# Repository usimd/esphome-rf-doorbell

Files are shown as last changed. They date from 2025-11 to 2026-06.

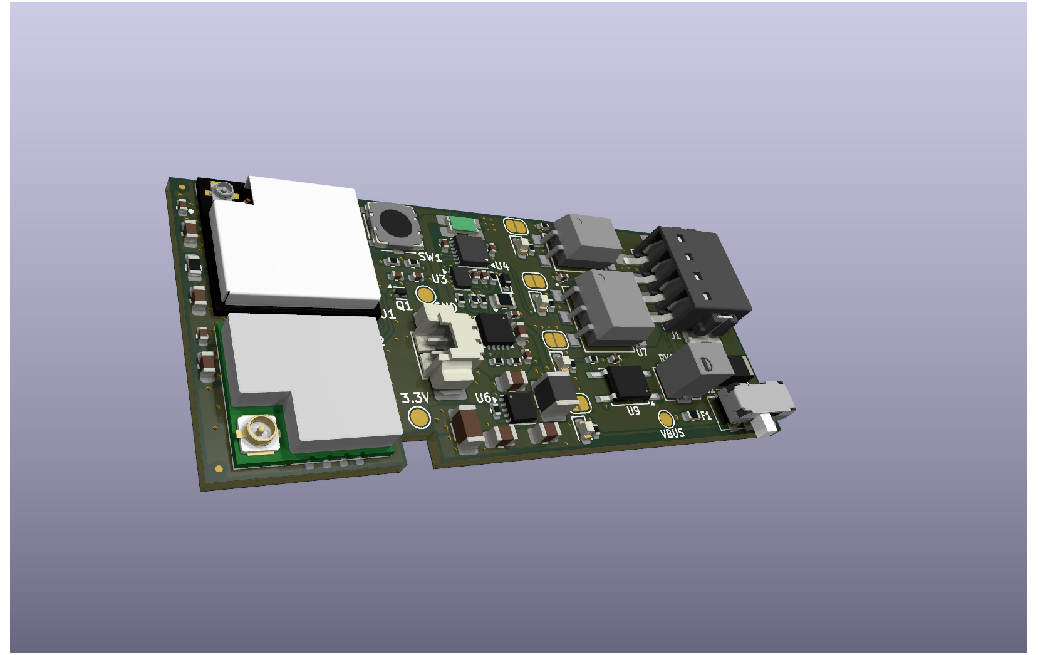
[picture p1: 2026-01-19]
base/esphome-rf-doorbell.png

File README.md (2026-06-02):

# ESPHome RF Doorbell





Battery-powered ESPHome doorbell hardware and firmware centered on the current Rev3 base board.

## Current Scope

- `base/` is the active hardware target.
- `esphome/doorbell.yaml` is the active firmware target.
- Rev3 uses ESP32-C6, LTC4079, ISL23315, MAX17260, and ESPHome's built-in `sx126x` support.
- `remote/` is intentionally kept as unfinished WIP hardware. It is not a supported production target.

## Rev3 Hardware Summary

| Ref | Part | Purpose |
|-----|---|---|
| U1 | LTC4079 | Li-ion charger |
| U3 | TPS63900 | Low-power buck-boost regulator |
| U4 | MAX17260 | Fuel gauge |
| U5 | LTV-354T | Doorbell input optocoupler |
| U6 | G3VM-31DR | Door opener relay |
| U7 | Wio-SX1262 | SX1262 radio module |
| U8 | G3VM-63ER | Bell mute relay |
| U9 | ESP32-C6-MINI-1 | Main MCU |
| U10 | ISL23315 | Digipot for charger control |

The base board already includes an SX126x receive path and that remains part of the intended design, even though the remote side is still unfinished.

## Repository Layout

```text
base/                    Active Rev3 KiCad project
datasheets/              Datasheets and hardware notes used during development
esphome/                 Active ESPHome firmware
esphome/components/      Custom ESPHome components
lib/                     Project KiCad footprints and symbols
remote/                  Unfinished remote hardware kept as WIP
```

## Firmware

The active firmware is in `esphome/doorbell.yaml`.

Implemented custom components:

- `doorbell_controller`: charger control, supply sensing, runtime sleep duration control
- `max17260`: fuel gauge driver with POR handling and learned-parameter persistence

Radio support uses ESPHome's built-in `sx126x` component rather than a custom RF stack.

## Build

From `esphome/`:

```bash
esphome compile doorbell.yaml
```

The configuration expects `esphome/secrets.yaml` to exist locally.

## Status

- Legacy firmware and custom components are removed from the supported path.
- The active Rev3 ESPHome config compiles successfully.
- CI builds the Rev3 firmware and the base KiCad project.
- `remote/` remains a hardware placeholder for future work and still contains legacy symbols/footprints inside that WIP design.

## Notes

- The ESP32-C6 pin usage in this design currently triggers ESPHome warnings for USB-Serial-JTAG pins and strapping pins. Those warnings reflect the current hardware choices and should be kept in mind during bring-up.
- `esphome/charging_test.yaml` and `esphome/charging_test_simple.yaml` currently exist as untracked placeholders and are not part of the supported firmware path.

## AISLER discount

In case you want to order this (or any other) project at AISLER, here's a 10€ discount code: `MakeInEurope-ZDCTN`

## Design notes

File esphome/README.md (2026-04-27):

# ESPHome Firmware

This directory contains the active Rev3 firmware for the base doorbell board.

## Active Files

- `doorbell.yaml`: main configuration used for builds
- `components/doorbell_controller/`: charger and power-management helper component
- `components/max17260/`: MAX17260 fuel gauge component
- `secrets.yaml`: local machine-specific secrets, ignored by git

## Rev3 Firmware Model

The supported firmware path is built around:

- ESP32-C6
- LTC4079 charger with ISL23315 digipot control
- MAX17260 fuel gauge
- ESPHome `sx126x` integration for the Wio-SX1262 module
- deep sleep wakeups from bell input, SX1262 DIO1, battery alert, and timer

There is no supported legacy firmware configuration in this directory anymore.

## Build

```bash
esphome compile doorbell.yaml
```

## OTA Recovery Helper

When the installed node is only reachable during short wake windows, use the repo-local helper to press the ESPHome `Restart` button over the native API and force the device into its existing `cold_boot_ota_window`.

```bash
../.venv/bin/python restart_into_ota_window.py --restart
```

Without `--restart`, the helper only prints the live device metadata and available button entities.
Add `--wait-timeout 180` if you want it to keep polling through the current deep-sleep cycle until the device wakes up.
The helper prefers `esphome-rf-doorbell.local` by default because the active firmware does not currently configure a fixed `manual_ip`.

## Runtime Notes

- `doorbell_controller` updates the real `deep_sleep` component sleep duration at runtime.
- `max17260` restores learned parameters from preferences and now treats POR-read failures as setup failures instead of healthy state.
- The firmware intentionally uses local external components from `components/`.

## Known Bring-Up Warnings

ESPHome currently warns that some selected GPIOs are USB-Serial-JTAG or strapping pins on ESP32-C6. These warnings are expected with the present hardware design and do not indicate a configuration parse failure.

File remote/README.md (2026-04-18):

# Remote WIP

`remote/` is intentionally kept as unfinished hardware work.

- It is not a supported production target.
- The old remote firmware implementation was removed.
- The current schematic and PCB may still contain legacy placeholder parts from earlier RF exploration.
- Keep this directory as hardware WIP until the remote architecture is redesigned around the current project direction.

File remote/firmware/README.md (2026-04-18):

# Remote Firmware WIP

There is currently no supported remote firmware implementation in this repository.

The previous remote firmware sources were removed. The remaining files in this directory are only leftover project workspace artifacts or reusable MCU-codegen scaffolding for future remote experiments.

Do not treat this directory as a buildable or supported firmware target in its current state.

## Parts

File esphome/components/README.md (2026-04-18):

# ESPHome Custom Components

This directory contains the custom components used by the active Rev3 firmware.

## Components

### `doorbell_controller`

Controls the LTC4079 support circuitry around the ISL23315 digipot and exposes:

- VINDPM threshold control
- charging enable/disable
- charge-disable override
- supply voltage measurement
- charge current estimation from `V_PROG`
- runtime deep sleep duration control

This component explicitly re-enables the ESP-IDF `esp_adc` component because ESPHome excludes it by default for faster builds.

### `max17260`

Fuel gauge driver for the MAX17260 with support for:

- battery percentage
- voltage, current, temperature
- remaining/full capacity
- cycle count
- time-to-empty and time-to-full
- device name and serial number
- POR detection and reinitialization
- persistence of learned parameters in ESPHome preferences

## Loading

`doorbell.yaml` loads both components from the local `components/` directory via `external_components`.

## Support Boundary

Only `doorbell_controller` and `max17260` are part of the supported Rev3 path here. Legacy custom components were removed from this repository path.

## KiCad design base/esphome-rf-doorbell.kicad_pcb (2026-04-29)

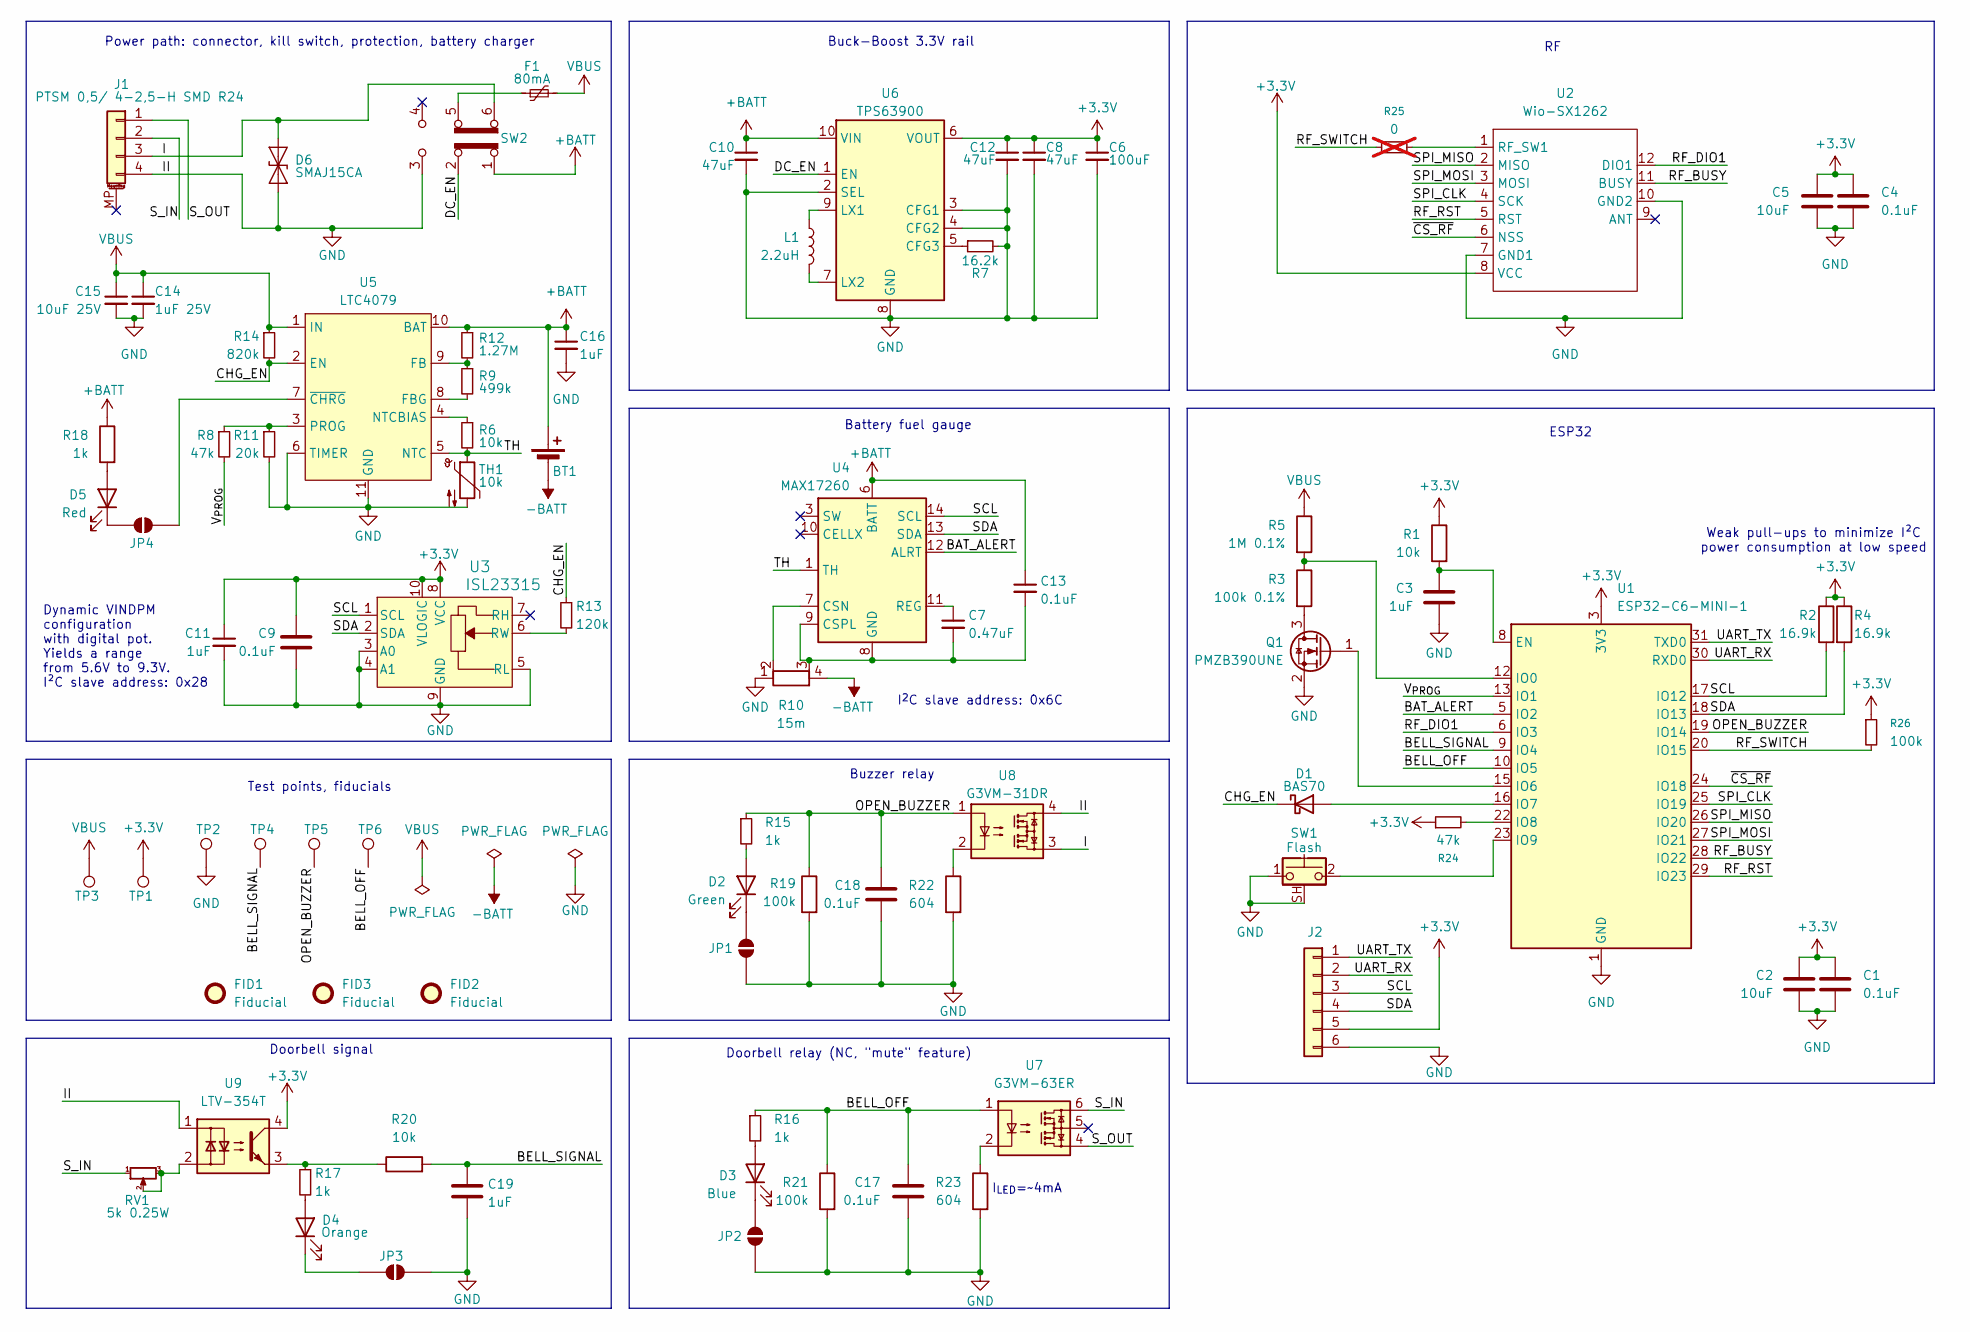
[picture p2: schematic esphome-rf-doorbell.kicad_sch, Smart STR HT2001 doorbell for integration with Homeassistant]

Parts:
BT1: Molex_PicoBlade_53261-0271_1x02-1MP_P1.25mm_Horizontal; MPN 532610271
C1, C4, C9, C13, C17, C18: 0.1uF; C_0402_1005Metric
C2, C5: 10uF; C_0603_1608Metric
C3: 1uF; C_0603_1608Metric
C6: 100uF; C_1206_3216Metric
C7: 0.47uF; C_0402_1005Metric
C8, C10, C12: 47uF; C_0805_2012Metric
C11, C16, C19: 1uF; C_0402_1005Metric
C14: 1uF 25V; C_0402_1005Metric
C15: 10uF 25V; C_0603_1608Metric
D1: BAS70; D_SOD-523; MPN BAS7002VH6327XTSA1
D2: Green; LED_0603_1608Metric
D3: Blue; LED_0603_1608Metric
D4: Orange; LED_0603_1608Metric
D5: Red; LED_0603_1608Metric
D6: SMAJ15CA; D_SMA; MPN SMAJ15CA
F1: 80mA; Fuse_0603_1608Metric; MPN SMD0603B008TF
FID1, FID2, FID3: Fiducial; Fiducial_0.5mm_Mask1mm
J1: PTSM 0,5/ 4-2,5-H SMD R24; PHOENIX_1702474; MPN 1702474
J2: Conn_01x06; Connector_PogoClamp_1.27mm
JP1, JP2, JP3, JP4: SolderJumper_2_Open; SolderJumper-2_P1.3mm_Open_RoundedPad1.0x1.5mm
L1: 2.2uH; L_1210_3225Metric; MPN DFE32CAH2R2MR0L
Q1: PMZB390UNE; Diodes_DFN1006-3; MPN PMZB390UNEYL
R1: 10k; R_0603_1608Metric
R2, R4: 16.9k; R_0402_1005Metric
R3: 100k 0.1%; C_0402_1005Metric
R5: 1M 0.1%; C_0402_1005Metric
R6, R20: 10k; R_0402_1005Metric
R7: 16.2k; R_0402_1005Metric
R8: 47k; R_0402_1005Metric
R9: 499k; R_0402_1005Metric
R10: 15m; R_Shunt_D1WRL1206; MPN D1WRL1206L4R015D-T5
R11: 20k; R_0402_1005Metric
R12: 1.27M; R_0402_1005Metric
R13: 120k; R_0402_1005Metric
R14: 820k; R_0805_2012Metric
R15, R16, R17, R18: 1k; R_0402_1005Metric
R19, R21: 100k; R_0402_1005Metric
R22, R23: 604; R_0402_1005Metric
R24: 47k; C_0402_1005Metric
R25: 0; C_0402_1005Metric; not fitted
R26: 100k; C_0402_1005Metric
RV1: 5k 0.25W; Potentiometer_Bourns_3214W_Vertical; MPN 3214W-1-502E
SW1: Flash; SW_SPST_Panasonic_EVQPL_3PL_5PL_PT_A08; MPN TVCU18015BPB
SW2: CL-SB-22A-11T; CL-SB-22A; MPN CL-SB-22A-11T
TH1: 10k; R_0603_1608Metric; MPN NTCS0603E3103FLT
TP1, TP2, TP3, TP4, TP5, TP6: TestPoint; TestPoint_Pad_D1.5mm
U1: ESP32-C6-MINI-1; XCVR_ESP32-C6-MINI-1U-N4; MPN ESP32-C6-MINI-1U-N4
U2: Wio-SX1262; Wio-SX1262 PCB Package; MPN WIO-SX1262
U3: ISL23315; L10_2P1X1P6A_INR; MPN ISL23315TFRUZ-T7A
U4: MAX17260; TDFN-14-1EP_3x3mm_P0.4mm_EP1.78x2.35mm; MPN MAX17260SETD+
U5: LTC4079; DFN-10-1EP_3x3mm_P0.5mm_EP1.65x2.38mm; MPN LTC4079EDD#TRPBF
U6: TPS63900; WSON-10-1EP_2.5x2.5mm_P0.5mm_EP1.2x2mm_ThermalVias; MPN TPS63900DSKR
U7: G3VM-63ER; G3VM-21ER; MPN G3VM-63ER
U8: G3VM-31DR; G3VM-21DR; MPN G3VM-31DR
U9: LTV-354T; SO-4_4.4x3.6mm_P2.54mm; MPN LTV-354T

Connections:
+3.3V: C1.1, C2.1, C4.1, C5.1, C6.1, C8.1, C9.1, C11.1, C12.1, J2.5, R1.1, R2.1, R4.1, R24.1, R26.1, TP1.1 (1_1), U1.3 (3V3), U2.8 (VCC), U3.8 (VCC), U3.10 (VLOGIC), U6.6 (VOUT), U9.4
+BATT: BT1.1 (+), C10.1, C13.1, C16.1, R12.1, R18.1, SW2.1 (A), U4.6 (BATT), U5.10 (BAT), U6.10 (VIN)
-BATT: BT1.2 (-), R10.4
/BAT_ALERT: U1.5 (IO2), U4.12 (ALRT)
/BELL_OFF: C17.1, R16.1, R21.1, TP6.1 (1_1), U1.10 (IO5), U7.1
/BELL_SIGNAL: C19.1, R20.2, TP4.1 (1_1), U1.9 (IO4)
/CHG_EN: D1.1 (K), R13.1, R14.2, U5.2 (EN)
/DC_EN: SW2.2 (B), U6.1 (EN)
/I: D6.2 (A2), J1.3, SW2.6 (C), U8.3
/OPEN_BUZZER: C18.1, R15.1, R19.1, TP5.1 (1_1), U1.19 (IO14), U8.1
/RF_BUSY: U1.28 (IO22), U2.11 (BUSY)
/RF_DIO1: U1.6 (IO3), U2.12 (DIO1)
/RF_RST: U1.29 (IO23), U2.5 (RST)
/RF_SWITCH: R25.1, R26.2, U1.20 (IO15)
/SCL: J2.3, R2.2, U1.17 (IO12), U3.1 (SCL), U4.14 (SCL)
/SDA: J2.4, R4.2, U1.18 (IO13), U3.2 (SDA), U4.13 (SDA)
/SPI_CLK: U1.25 (IO19), U2.4 (SCK)
/SPI_MISO: U1.26 (IO20), U2.2 (MISO)
/SPI_MOSI: U1.27 (IO21), U2.3 (MOSI)
/S_IN: J1.2, RV1.1, U7.6
/S_OUT: J1.1, U7.4
/TH: R6.2, TH1.1, U4.1 (TH), U5.5 (NTC)
/UART_RX: J2.2, U1.30 (RXD0)
/UART_TX: J2.1, U1.31 (TXD0)
/V_{PROG}: R8.2, U1.13 (IO1)
/~CS_RF: U1.24 (IO18), U2.6 (NSS)
GND: C1.2, C2.2, C3.2, C4.2, C5.2, C6.2, C8.2, C9.2, C10.2, C11.2, C12.2, C14.2, C15.2, C16.2, C17.2, C18.2, C19.2, D6.1 (A1), J1.4, J2.6, JP1.1 (A), JP2.1 (A), JP3.2 (B), Q1.2 (S), R7.2, R10.1, R11.2, R19.2, R21.2, R22.2, R23.2, SW1.1, SW1.SH (B), SW2.3 (C), TH1.2, TP2.1 (1_1), U1.1 (GND), U1.2 (GND), U1.11 (GND), U1.14 (GND), U1.36 (GND), U1.37 (GND), U1.38 (GND), U1.39 (GND), U1.40 (GND), U1.41 (GND), U1.42 (GND), U1.43 (GND), U1.44 (GND), U1.45 (GND), U1.46 (GND), U1.47 (GND), U1.48 (GND), U1.49 (GND), U1.50 (GND), U1.51 (GND), U1.52 (GND), U1.53 (GND), U2.7 (GND1), U2.10 (GND2), U3.3 (A0), U3.4 (A1), U3.5 (RL), U3.9 (GND), U5.6 (TIMER), U5.11 (GND), U6.2 (SEL), U6.3 (CFG1), U6.4 (CFG2), U6.8 (GND), U6.11 (GND), U8.4, U9.1
unnamed: D1.2 (A), U1.16 (IO7)
unnamed: D2.2 (A), R15.2
unnamed: D2.1 (K), JP1.2 (B)
unnamed: D3.2 (A), R16.2
unnamed: D3.1 (K), JP2.2 (B)
unnamed: D4.2 (A), R17.2
unnamed: D4.1 (K), JP3.1 (A)
unnamed: D5.2 (A), R18.2
unnamed: D5.1 (K), JP4.2 (B)
unnamed: F1.1, SW2.5 (B)
unnamed: JP4.1 (A), U5.7 (~CHRG)
unnamed: Q1.3 (D), R3.2
unnamed: Q1.1 (G), U1.15 (IO6)
unnamed: R17.1, R20.1, U9.3
unnamed: R22.1, U8.2
unnamed: R23.1, U7.2
unnamed: RV1.2, RV1.3, U9.2
unnamed: C3.1, R1.2, U1.8 (EN)
unnamed: R3.1, R5.2, U1.12 (IO0)
unnamed: R24.2, U1.22 (IO8)
unnamed: SW1.2, U1.23 (IO9)
unnamed: R25.2, U2.1 (RF_SW1)
unnamed: R13.2, U3.6 (RW)
unnamed: R10.2, U4.7 (CSN)
unnamed: C7.2, C13.2, R10.3, U4.8 (GND), U4.9 (CSPL), U4.15 (GND)
unnamed: C7.1, U4.11 (REG)
unnamed: R9.1, R12.2, U5.9 (FB)
unnamed: R9.2, U5.8 (FBG)
unnamed: R6.1, U5.4 (NTCBIAS)
unnamed: R8.1, R11.1, U5.3 (PROG)
unnamed: R7.1, U6.5 (CFG3)
unnamed: L1.1, U6.9 (LX1)
unnamed: L1.2, U6.7 (LX2)
VBUS: C14.1, C15.1, F1.2, R5.1, R14.1, TP3.1 (1_1), U5.1 (IN)

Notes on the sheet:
Dynamic VINDPM configuration with digital pot. Yields a range from 5.6V to 9.3V. I²C slave address: 0x28
Test points, fiducials
Battery fuel gauge
ESP32
Weak pull-ups to minimize I²C power consumption at low speed
Doorbell signal
I_{LED}=~4mA
Buzzer relay
Doorbell relay (NC, "mute" feature)
Buck-Boost 3.3V rail
Power path: connector, kill switch, protection, battery charger
I^{2}C slave address: 0x6C

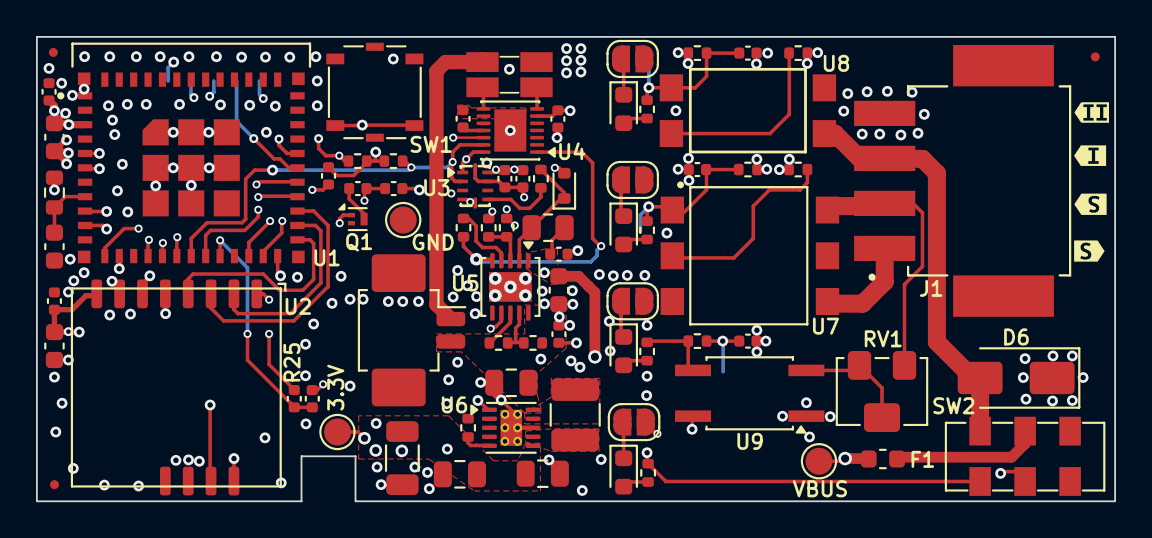
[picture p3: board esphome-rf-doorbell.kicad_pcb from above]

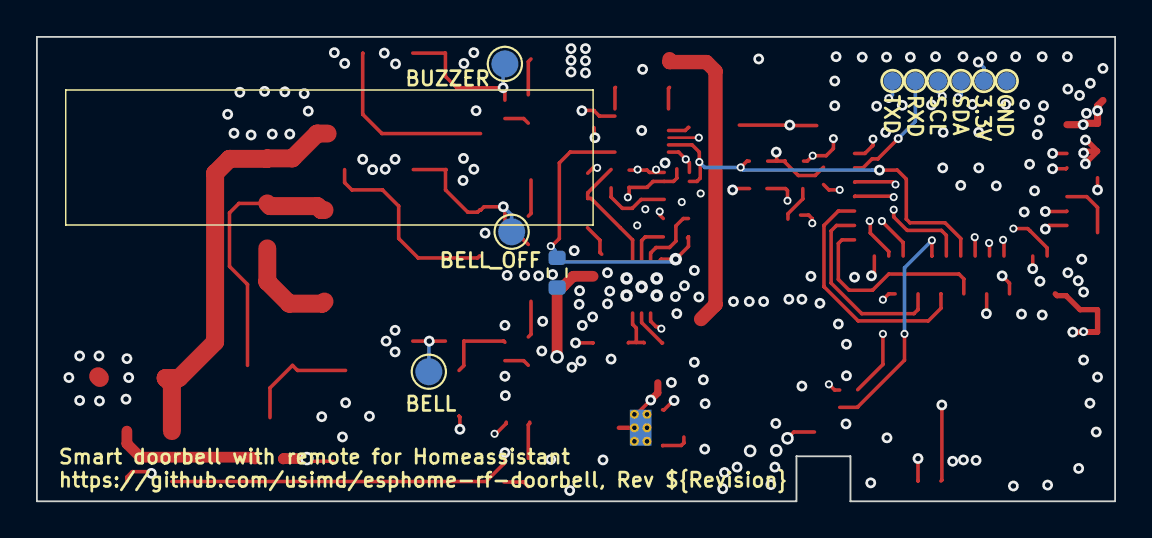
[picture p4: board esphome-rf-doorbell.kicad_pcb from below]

Board: 4 copper layers, 59.9 x 25.8 mm, 87 parts (5 on the bottom side), 61 nets.

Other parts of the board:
kibuzzard-696E5F1B: G***; kibuzzard-696E5F1B
kibuzzard-696E5F3B: G***; kibuzzard-696E5F3B
kibuzzard-696E5F26: G***; kibuzzard-696E5F26
kibuzzard-696E5F32: G***; kibuzzard-696E5F32

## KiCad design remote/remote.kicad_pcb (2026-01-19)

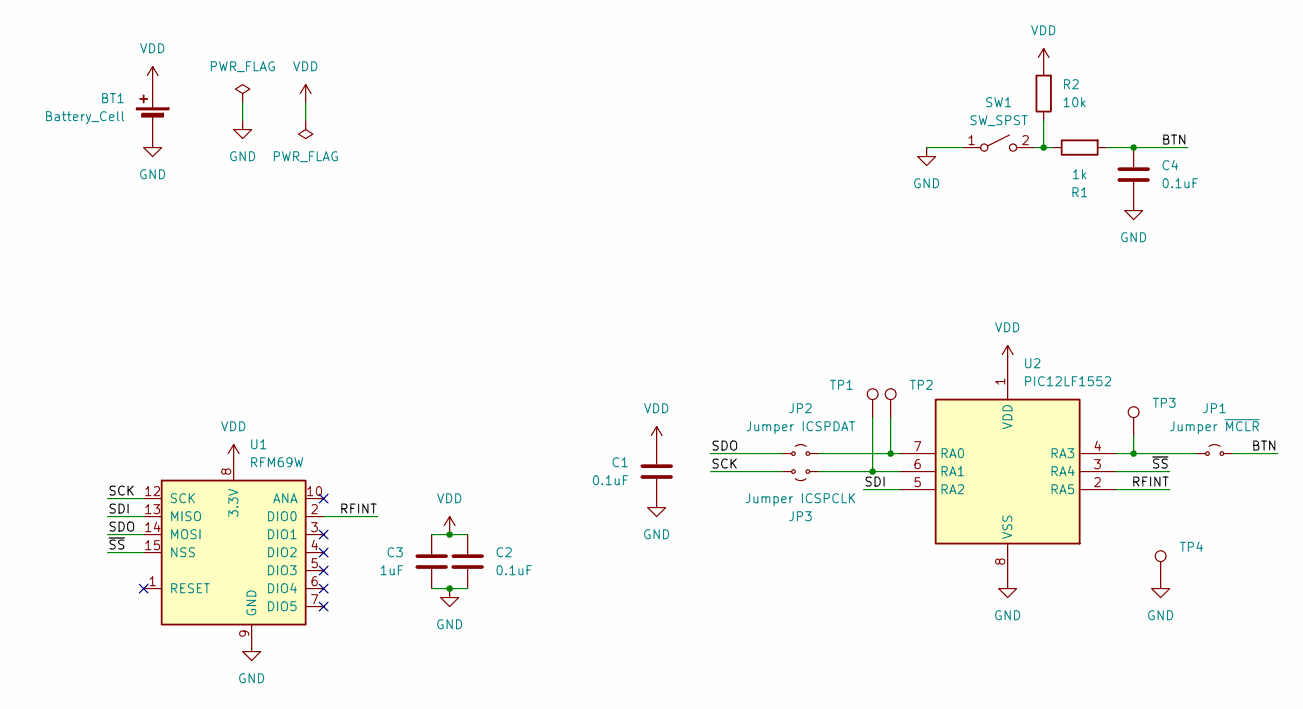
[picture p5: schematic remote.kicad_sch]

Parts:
BT1: Battery_Cell; BatteryHolder_Keystone_1060_1x2032
C1, C2, C4: 0.1uF; C_0603_1608Metric_Pad1.08x0.95mm_HandSolder
C3: 1uF; C_0603_1608Metric_Pad1.08x0.95mm_HandSolder
JP1: Jumper ~{MCLR}; SolderJumper-2_P1.3mm_Open_RoundedPad1.0x1.5mm
JP2: Jumper ICSPDAT; SolderJumper-2_P1.3mm_Open_RoundedPad1.0x1.5mm
JP3: Jumper ICSPCLK; SolderJumper-2_P1.3mm_Open_RoundedPad1.0x1.5mm
R1: 1k; R_0603_1608Metric_Pad0.98x0.95mm_HandSolder
R2: 10k; R_0603_1608Metric_Pad0.98x0.95mm_HandSolder
SW1: SW_SPST; SW_SPST_Panasonic_EVQPL_3PL_5PL_PT_A15
TP1, TP2, TP3, TP4: TestPoint; TestPoint_Keystone_5000-5004_Miniature
U1: RFM69W; HOPERF_RFM69HW
U2: PIC12LF1552; MSOP-8_3x3mm_P0.65mm

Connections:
/BTN: C4.1, JP1.2 (B), R1.2
/RFINT: U1.2 (DIO0), U2.2 (RA5)
/SCK: JP3.1 (A), U1.12 (SCK)
/SDI: U1.13 (MISO), U2.5 (RA2)
/SDO: JP2.1 (A), U1.14 (MOSI)
/~SS: U1.15 (NSS), U2.3 (RA4)
GND: BT1.2 (-), C1.2, C2.2, C3.2, C4.2, SW1.1 (A), TP4.1, U1.9 (GND), U1.11 (GND), U2.8 (VSS)
unnamed: JP1.1 (A), TP3.1, U2.4 (RA3)
unnamed: JP2.2 (B), TP2.1, U2.7 (RA0)
unnamed: JP3.2 (B), TP1.1, U2.6 (RA1)
unnamed: R1.1, R2.1, SW1.2 (B)
VDD: BT1.1 (+), C1.1, C2.1, C3.1, R2.2, U1.8 (3.3V), U2.1 (VDD)

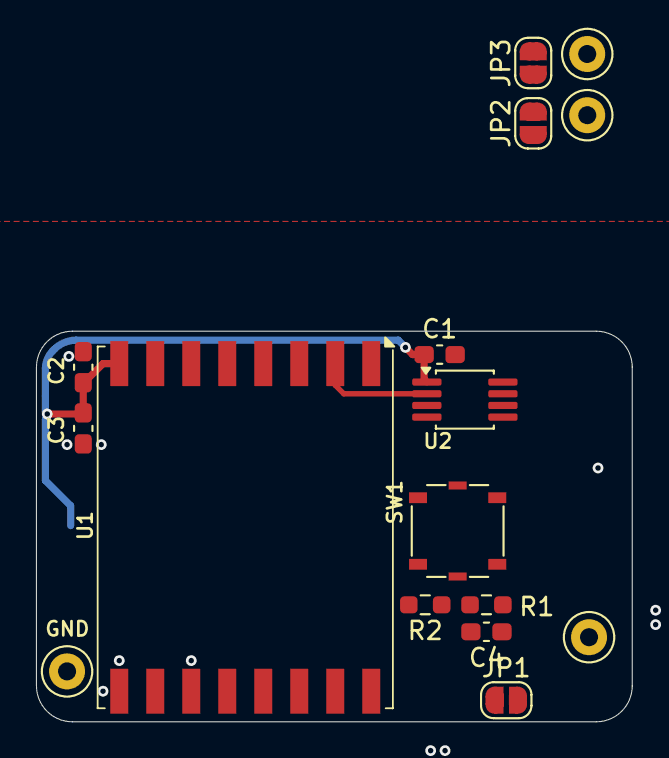
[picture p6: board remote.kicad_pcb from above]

Board: 2 copper layers, 33.1 x 21.7 mm, 17 parts (1 on the bottom side), 12 nets.

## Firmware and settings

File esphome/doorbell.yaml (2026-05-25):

# =============================================================================
# ESPHome RF Doorbell - Rev3 Hardware Configuration
# =============================================================================
# Hardware: ESP32-C6-MINI-1, LTC4079 charger, MAX17260 fuel gauge, Wio-SX1262
# 
# Rev3 hardware summary:
#   - MCU: ESP32-C6-MINI-1
#   - Charger: LTC4079 controlled via ISL23315 digipot
#   - RF: Wio-SX1262 LoRa via ESPHome's sx126x component
#   - Buck: TPS63900 for ultra-low quiescent current
#
# =============================================================================

esphome:
  name: esphome-rf-doorbell
  friendly_name: Doorbell

  includes:
    - components/max17260/max17260.h
  
  on_boot:
    - priority: -100  # Runs last after all components initialized
      then:
        - script.execute: handle_boot_wakeup

# =============================================================================
# ESP32-C6 configuration (Rev3 custom hardware)
# =============================================================================
esp32:
  board: esp32-c6-devkitm-1
  variant: esp32c6
  framework:
    type: esp-idf
    version: recommended

# =============================================================================
# Deep Sleep Configuration for Low Power Operation
# =============================================================================
# Wake sources:
#   1. GPIO4 (Bell Signal) - Doorbell pressed, stay awake 60s for user interaction
#      Uses the ESP32-C6 GPIO wake path because runtime GPIO4 works, but ext1 wake on
#      this pin has been unreliable on bench.
#   2. GPIO2 (BAT_ALERT MAX17260) - Battery alert, update sensor and quick sleep
#      Uses ext1 ANY_LOW because the alert line is open-drain active-low.
#   3. Timer (300s default, HA-controlled) - Periodic sync of HA desired state and diagnostics
# Power target: TPS63900 provides <400nA quiescent, total deep sleep <10uA
# =============================================================================
deep_sleep:
  id: deep_sleep_control
  sleep_duration: 300s
  # On ESP32-C6, runtime GPIO4 sensing works reliably, so use the single-pin GPIO wake
  # path for the bell input and reserve ext1 for the active-low battery alert.
  wakeup_pin:
    number: GPIO4
    mode:
      input: true
      pulldown: true
    inverted: false
    allow_other_uses: true
  wakeup_pin_mode: KEEP_AWAKE
  esp32_ext1_wakeup:
    pins:
      - number: GPIO2   # Battery alert (active LOW open-drain)
        allow_other_uses: true
    mode: ANY_LOW

# Enable logging
logger:
  level: INFO
  baud_rate: 115200
  hardware_uart: UART0

# Time component for timestamps
time:
  - platform: homeassistant
    id: esphome_time

api:
  homeassistant_states: true
  encryption:
    key: !secret doorbell_api_encryption_key

ota:
  - platform: esphome
    password: !secret doorbell_ota_password

wifi:
  ssid: !secret wifi_ssid
  password: !secret wifi_password
  fast_connect: true
  output_power: 15dB
  ap:
    ssid: "Doorbell Fallback Hotspot"
    password: !secret doorbell_ap_password
    ap_timeout: 30s

captive_portal:

# =============================================================================
# Persistent Diagnostics
# =============================================================================
globals:
  - id: wake_count_total
    type: uint32_t
    restore_value: true
    initial_value: '0'

  - id: wake_count_doorbell
    type: uint32_t
    restore_value: true
    initial_value: '0'

  - id: wake_count_timer
    type: uint32_t
    restore_value: true
    initial_value: '0'

  - id: wake_count_battery
    type: uint32_t
    restore_value: true
    initial_value: '0'

  - id: wake_count_cold_boot
    type: uint32_t
    restore_value: true
    initial_value: '0'

  - id: bell_event_count
    type: uint32_t
    restore_value: true
    initial_value: '0'

  - id: last_wake_reason
    type: std::string
    restore_value: true
    max_restore_data_length: 31
    initial_value: '"unknown"'

  - id: last_mute_sync_status
    type: std::string
    restore_value: true
    max_restore_data_length: 31
    initial_value: '"startup"'

  - id: last_bell_millis
    type: uint32_t
    restore_value: false
    initial_value: '0'

# =============================================================================
# External Components
# =============================================================================
external_components:
  - source:
      type: local
      path: components
    components: [max17260, doorbell_controller]

# =============================================================================
# I2C Bus (shared by doorbell_controller and max17260)
# =============================================================================
i2c:
  sda: GPIO13
  scl: GPIO12
  frequency: 100kHz  # Lower frequency for weak pull-ups on PCB
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

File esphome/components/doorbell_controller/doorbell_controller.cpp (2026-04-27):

#include "doorbell_controller.h"
#include "esphome/core/log.h"
#include "esphome/core/application.h"

#ifdef USE_ESP32
#include "esp_sleep.h"
#include "esp_adc/adc_oneshot.h"
#endif

namespace esphome {
namespace doorbell_controller {

static const char *const TAG = "doorbell_controller";

// =============================================================================
// DoorbellControllerComponent Implementation
// =============================================================================

void DoorbellControllerComponent::setup() {
  ESP_LOGCONFIG(TAG, "Setting up Doorbell Controller...");

  // Initialize charge disable pin if configured
  if (this->charge_disable_pin_ != nullptr) {
    this->charge_disable_pin_->setup();
    this->charge_disable_pin_->pin_mode(gpio::FLAG_INPUT);  // High-Z default
    ESP_LOGD(TAG, "Charge disable pin configured (high-Z mode)");
  }

  // Initialize supply sense enable pin if configured
  if (this->supply_sense_enable_pin_ != nullptr) {
    this->supply_sense_enable_pin_->setup();
    this->supply_sense_enable_pin_->digital_write(false);  // Off by default
    ESP_LOGD(TAG, "Supply sense enable pin configured");
  }

  // Read current wiper value from ISL23315
  uint8_t wiper;
  if (this->read_wiper(wiper)) {
    this->current_wiper_ = wiper;
    ESP_LOGI(TAG, "ISL23315 wiper value: %d (%.1fV VINDPM threshold)", 
             wiper, this->wiper_to_voltage(wiper));
    this->update_wiper_sensor_();
  } else {
    ESP_LOGW(TAG, "Failed to read ISL23315 wiper value, using default");
    this->current_wiper_ = ISL23315_WIPER_DEFAULT;
  }
}

void DoorbellControllerComponent::update() {
  // Called on wakeup or periodic update - read power state
  this->update_power_sensors_();
}

void DoorbellControllerComponent::dump_config() {
  ESP_LOGCONFIG(TAG, "Doorbell Controller:");
  ESP_LOGCONFIG(TAG, "  VINDPM Divider: R_high=%.0fΩ, R_low=%.0fΩ, R_pot=%.0fΩ", 
                this->r_high_, this->r_low_, this->r_pot_);
  ESP_LOGCONFIG(TAG, "  Supply Divider Ratio: %.1f", this->supply_divider_ratio_);
  ESP_LOGCONFIG(TAG, "  R_PROG: %.0fΩ (max charge current: %.1fmA)", 
                this->r_prog_, 250.0f * LTC4079_VEN_THRESHOLD / this->r_prog_ * 1000.0f);
  ESP_LOGCONFIG(TAG, "  R_SERIES_VPROG: %.0fΩ (ADC isolation resistor)", this->r_series_vprog_);
  ESP_LOGCONFIG(TAG, "  Current wiper: %d (VINDPM: %.2fV)", 
                this->current_wiper_, this->wiper_to_voltage(this->current_wiper_));
  ESP_LOGCONFIG(TAG, "  Sleep Duration: %ds", this->sleep_duration_);
  
  if (this->charge_disable_pin_ != nullptr) {
    LOG_PIN("  Charge Disable Pin: ", this->charge_disable_pin_);
  }
  if (this->supply_sense_enable_pin_ != nullptr) {
    LOG_PIN("  Supply Sense Enable Pin: ", this->supply_sense_enable_pin_);
  }
  ESP_LOGCONFIG(TAG, "  Supply ADC Pin: GPIO%d", this->supply_adc_pin_);
  ESP_LOGCONFIG(TAG, "  V_PROG ADC Pin: GPIO%d", this->vprog_adc_pin_);
}

// =============================================================================
// ISL23315 Digipot Control
// =============================================================================

bool DoorbellControllerComponent::read_wiper(uint8_t &value) {
  uint8_t cmd = ISL23315_WIPER_INSTRUCTION;
  
  // Use write_read() for consecutive write and read operations
  i2c::ErrorCode err = this->write_read(&cmd, 1, &value, 1);
  if (err != i2c::ERROR_OK) {
    ESP_LOGE(TAG, "ISL23315 read wiper failed: %d", err);
    return false;
  }
  
  return true;
}

bool DoorbellControllerComponent::write_wiper(uint8_t value) {
  uint8_t data[2] = {ISL23315_WIPER_INSTRUCTION, value};
  
  i2c::ErrorCode err = this->write(data, 2);
  if (err != i2c::ERROR_OK) {
    ESP_LOGE(TAG, "ISL23315 write wiper failed: %d", err);
    return false;
  }
  
  this->current_wiper_ = value;
  this->update_wiper_sensor_();
  
  ESP_LOGD(TAG, "ISL23315 wiper set to %d (VINDPM: %.2fV)", 
           value, this->wiper_to_voltage(value));
  return true;
}

// =============================================================================
// VINDPM Threshold Calculation
// =============================================================================

float DoorbellControllerComponent::wiper_to_voltage(uint8_t wiper_value) {
  float r_wiper = (static_cast<float>(wiper_value) / 255.0f) * this->r_pot_;
  float r_total = this->r_high_ + this->r_low_ + r_wiper;
  float r_bottom = this->r_low_ + r_wiper;
  return LTC4079_VEN_THRESHOLD * r_total / r_bottom;
}

uint8_t DoorbellControllerComponent::voltage_to_wiper(float voltage) {
  float ven = LTC4079_VEN_THRESHOLD;
  float r_wiper = (ven * (this->r_high_ + this->r_low_) - voltage * this->r_low_) / (voltage - ven);
  
  if (r_wiper < 0) r_wiper = 0;
  if (r_wiper > this->r_pot_) r_wiper = this->r_pot_;
  
  return static_cast<uint8_t>((r_wiper / this->r_pot_) * 255.0f);
}

bool DoorbellControllerComponent::set_vindpm_threshold(float voltage) {
  uint8_t wiper = this->voltage_to_wiper(voltage);
  
  if (!this->write_wiper(wiper)) {
    return false;
  }
  
  ESP_LOGI(TAG, "VINDPM threshold set to %.2fV (wiper=%d)", voltage, wiper);
  return true;
}

bool DoorbellControllerComponent::get_vindpm_threshold(float &voltage) {
  uint8_t wiper;
  if (!this->read_wiper(wiper)) {
    return false;
  }
  
  voltage = this->wiper_to_voltage(wiper);
  return true;
}

// =============================================================================
// Charging Control
// =============================================================================

bool DoorbellControllerComponent::enable_charging() {
  ESP_LOGI(TAG, "Enabling charging (wiper=255, VINDPM ~%.1fV)", 
           this->wiper_to_voltage(ISL23315_WIPER_MAX));
  return this->write_wiper(ISL23315_WIPER_MAX);
}

bool DoorbellControllerComponent::disable_charging() {
  ESP_LOGI(TAG, "Disabling charging via VINDPM (wiper=0, VINDPM ~%.1fV)", 
           this->wiper_to_voltage(ISL23315_WIPER_MIN));
  return this->write_wiper(ISL23315_WIPER_MIN);
}

void DoorbellControllerComponent::set_charge_override(bool disable) {
  if (this->charge_disable_pin_ == nullptr) {
    ESP_LOGW(TAG, "Charge disable pin not configured");
    return;
  }
  
  if (disable) {
    this->charge_disable_pin_->pin_mode(gpio::FLAG_OUTPUT);
    this->charge_disable_pin_->digital_write(false);
    ESP_LOGI(TAG, "Charge override ACTIVE - charging force disabled");
  } else {
    this->charge_disable_pin_->pin_mode(gpio::FLAG_INPUT);
    ESP_LOGI(TAG, "Charge override RELEASED - VINDPM controls charging");
  }
  
  this->charge_override_active_ = disable;
}

// =============================================================================
// Supply Voltage Measurement
// =============================================================================
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

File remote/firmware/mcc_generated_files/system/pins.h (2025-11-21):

/**
 * Generated Pins header File
 * 
 * @file pins.h
 * 
 * @defgroup  pinsdriver Pins Driver
 * 
 * @brief This is generated driver header for pins. 
 *        This header file provides APIs for all pins selected in the GUI.
 *
 * @version Driver Version  3.0.0
*/

/*
© [2025] Microchip Technology Inc. and its subsidiaries.

    Subject to your compliance with these terms, you may use Microchip 
    software and any derivatives exclusively with Microchip products. 
    You are responsible for complying with 3rd party license terms  
    applicable to your use of 3rd party software (including open source  
    software) that may accompany Microchip software. SOFTWARE IS ?AS IS.? 
    NO WARRANTIES, WHETHER EXPRESS, IMPLIED OR STATUTORY, APPLY TO THIS 
    SOFTWARE, INCLUDING ANY IMPLIED WARRANTIES OF NON-INFRINGEMENT,  
    MERCHANTABILITY, OR FITNESS FOR A PARTICULAR PURPOSE. IN NO EVENT 
    WILL MICROCHIP BE LIABLE FOR ANY INDIRECT, SPECIAL, PUNITIVE, 
    INCIDENTAL OR CONSEQUENTIAL LOSS, DAMAGE, COST OR EXPENSE OF ANY 
    KIND WHATSOEVER RELATED TO THE SOFTWARE, HOWEVER CAUSED, EVEN IF 
    MICROCHIP HAS BEEN ADVISED OF THE POSSIBILITY OR THE DAMAGES ARE 
    FORESEEABLE. TO THE FULLEST EXTENT ALLOWED BY LAW, MICROCHIP?S 
    TOTAL LIABILITY ON ALL CLAIMS RELATED TO THE SOFTWARE WILL NOT 
    EXCEED AMOUNT OF FEES, IF ANY, YOU PAID DIRECTLY TO MICROCHIP FOR 
    THIS SOFTWARE.
*/

#ifndef PINS_H
#define PINS_H

#include <xc.h>

#define INPUT   1
#define OUTPUT  0

#define HIGH    1
#define LOW     0

#define ANALOG      1
#define DIGITAL     0

#define PULL_UP_ENABLED      1
#define PULL_UP_DISABLED     0

// get/set IO_RA0 aliases
#define IO_RA0_TRIS                 TRISAbits.TRISA0
#define IO_RA0_LAT                  LATAbits.LATA0
#define IO_RA0_PORT                 PORTAbits.RA0
#define IO_RA0_WPU                  WPUAbits.WPUA0
#define IO_RA0_OD                   ODCONAbits.
#define IO_RA0_ANS                  ANSELAbits.ANSA0
#define IO_RA0_SetHigh()            do { LATAbits.LATA0 = 1; } while(0)
#define IO_RA0_SetLow()             do { LATAbits.LATA0 = 0; } while(0)
#define IO_RA0_Toggle()             do { LATAbits.LATA0 = ~LATAbits.LATA0; } while(0)
#define IO_RA0_GetValue()           PORTAbits.RA0
#define IO_RA0_SetDigitalInput()    do { TRISAbits.TRISA0 = 1; } while(0)
#define IO_RA0_SetDigitalOutput()   do { TRISAbits.TRISA0 = 0; } while(0)
#define IO_RA0_SetPullup()          do { WPUAbits.WPUA0 = 1; } while(0)
#define IO_RA0_ResetPullup()        do { WPUAbits.WPUA0 = 0; } while(0)
#define IO_RA0_SetPushPull()        do { ODCONAbits. = 0; } while(0)
#define IO_RA0_SetOpenDrain()       do { ODCONAbits. = 1; } while(0)
#define IO_RA0_SetAnalogMode()      do { ANSELAbits.ANSA0 = 1; } while(0)
#define IO_RA0_SetDigitalMode()     do { ANSELAbits.ANSA0 = 0; } while(0)
// get/set IO_RA1 aliases
#define IO_RA1_TRIS                 TRISAbits.TRISA1
#define IO_RA1_LAT                  LATAbits.LATA1
#define IO_RA1_PORT                 PORTAbits.RA1
#define IO_RA1_WPU                  WPUAbits.WPUA1
#define IO_RA1_OD                   ODCONAbits.
#define IO_RA1_ANS                  ANSELAbits.ANSA1
#define IO_RA1_SetHigh()            do { LATAbits.LATA1 = 1; } while(0)
#define IO_RA1_SetLow()             do { LATAbits.LATA1 = 0; } while(0)
#define IO_RA1_Toggle()             do { LATAbits.LATA1 = ~LATAbits.LATA1; } while(0)
#define IO_RA1_GetValue()           PORTAbits.RA1
#define IO_RA1_SetDigitalInput()    do { TRISAbits.TRISA1 = 1; } while(0)
#define IO_RA1_SetDigitalOutput()   do { TRISAbits.TRISA1 = 0; } while(0)
#define IO_RA1_SetPullup()          do { WPUAbits.WPUA1 = 1; } while(0)
#define IO_RA1_ResetPullup()        do { WPUAbits.WPUA1 = 0; } while(0)
#define IO_RA1_SetPushPull()        do { ODCONAbits. = 0; } while(0)
#define IO_RA1_SetOpenDrain()       do { ODCONAbits. = 1; } while(0)
#define IO_RA1_SetAnalogMode()      do { ANSELAbits.ANSA1 = 1; } while(0)
#define IO_RA1_SetDigitalMode()     do { ANSELAbits.ANSA1 = 0; } while(0)
// get/set IO_RA2 aliases
#define IO_RA2_TRIS                 TRISAbits.TRISA2
#define IO_RA2_LAT                  LATAbits.LATA2
#define IO_RA2_PORT                 PORTAbits.RA2
#define IO_RA2_WPU                  WPUAbits.WPUA2
#define IO_RA2_OD                   ODCONAbits.
#define IO_RA2_ANS                  ANSELAbits.ANSA2
#define IO_RA2_SetHigh()            do { LATAbits.LATA2 = 1; } while(0)
#define IO_RA2_SetLow()             do { LATAbits.LATA2 = 0; } while(0)
#define IO_RA2_Toggle()             do { LATAbits.LATA2 = ~LATAbits.LATA2; } while(0)
#define IO_RA2_GetValue()           PORTAbits.RA2
#define IO_RA2_SetDigitalInput()    do { TRISAbits.TRISA2 = 1; } while(0)
#define IO_RA2_SetDigitalOutput()   do { TRISAbits.TRISA2 = 0; } while(0)
#define IO_RA2_SetPullup()          do { WPUAbits.WPUA2 = 1; } while(0)
#define IO_RA2_ResetPullup()        do { WPUAbits.WPUA2 = 0; } while(0)
#define IO_RA2_SetPushPull()        do { ODCONAbits. = 0; } while(0)
#define IO_RA2_SetOpenDrain()       do { ODCONAbits. = 1; } while(0)
#define IO_RA2_SetAnalogMode()      do { ANSELAbits.ANSA2 = 1; } while(0)
#define IO_RA2_SetDigitalMode()     do { ANSELAbits.ANSA2 = 0; } while(0)
// get/set IO_RA3 aliases
#define BTN_TRIS                 TRISAbits.TRISA3
#define BTN_LAT                  LATAbits.
#define BTN_PORT                 PORTAbits.RA3
#define BTN_WPU                  WPUAbits.WPUA3
#define BTN_OD                   ODCONAbits.
#define BTN_ANS                  ANSELAbits.
#define BTN_SetHigh()            do { LATAbits. = 1; } while(0)
#define BTN_SetLow()             do { LATAbits. = 0; } while(0)
#define BTN_Toggle()             do { LATAbits. = ~LATAbits.; } while(0)
#define BTN_GetValue()           PORTAbits.RA3
#define BTN_SetDigitalInput()    do { TRISAbits.TRISA3 = 1; } while(0)
#define BTN_SetDigitalOutput()   do { TRISAbits.TRISA3 = 0; } while(0)
#define BTN_SetPullup()          do { WPUAbits.WPUA3 = 1; } while(0)
#define BTN_ResetPullup()        do { WPUAbits.WPUA3 = 0; } while(0)
#define BTN_SetPushPull()        do { ODCONAbits. = 0; } while(0)
#define BTN_SetOpenDrain()       do { ODCONAbits. = 1; } while(0)
#define BTN_SetAnalogMode()      do { ANSELAbits. = 1; } while(0)
#define BTN_SetDigitalMode()     do { ANSELAbits. = 0; } while(0)
#define RA3_SetInterruptHandler  BTN_SetInterruptHandler
// get/set IO_RA4 aliases
#define CS_TRIS                 TRISAbits.TRISA4
#define CS_LAT                  LATAbits.LATA4
#define CS_PORT                 PORTAbits.RA4
#define CS_WPU                  WPUAbits.WPUA4
#define CS_OD                   ODCONAbits.
#define CS_ANS                  ANSELAbits.ANSA4
#define CS_SetHigh()            do { LATAbits.LATA4 = 1; } while(0)
#define CS_SetLow()             do { LATAbits.LATA4 = 0; } while(0)
#define CS_Toggle()             do { LATAbits.LATA4 = ~LATAbits.LATA4; } while(0)
#define CS_GetValue()           PORTAbits.RA4
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

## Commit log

2025-11-21 Replace RF module, finish routing
    [esphome-rf-doorbell.kicad_pcb, esphome-rf-doorbell.kicad_sch]
2025-11-21 Add remote and firmware
    [esphome-rf-doorbell.kicad_pcb, esphome-rf-doorbell.kicad_sch, remote.kicad_pcb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]
2025-11-21 Add checkout steps to KiCAD CI
2025-11-21 Fix ERC
    [esphome-rf-doorbell.kicad_sch, remote.kicad_pcb, remote.kicad_sch]
2025-11-21 Fix DRC and remove cmake parallel
    [esphome-rf-doorbell.kicad_pcb]
2025-12-20 New board rev, frist draft of ESPHome component
    [esphome-rf-doorbell.kicad_pcb, esphome-rf-doorbell.kicad_sch]
2025-12-20 Sensor definition in init
2025-12-21 Add i2c debug logging
2025-12-21 Fix charger and fuel gauge registers
2025-12-21 Fix IChgTerm calculation: 320 for 20mA with 25mΩ resistor
2025-12-21 Add verbose I2C write debugging to identify configuration failure point
2025-12-21 Fix read_register_word_ call - use reference not pointer
    [esphome-rf-doorbell.kicad_pcb, esphome-rf-doorbell.kicad_sch]
2025-12-21 Set VBUS_OVP to maximum (0xFF) to test if fault clears - chip masks to 0xF0 = 15.6V
2025-12-22 Fix fuel gauge I2C impl
2025-12-22 Fix battery scaling factor
2025-12-29 Update interrupt pin mapping
    [esphome-rf-doorbell.kicad_pcb, esphome-rf-doorbell.kicad_sch]
2025-12-29 Fix paths
    [esphome-rf-doorbell.kicad_pcb, remote.kicad_pcb]
2025-12-29 Fix DRC violations
    [esphome-rf-doorbell.kicad_pcb]
2026-01-01 Better charge status debugging
2026-01-02 Update schematics with latest findings
    [esphome-rf-doorbell.kicad_pcb, esphome-rf-doorbell.kicad_sch]
2026-01-02 Fix ADC readings
2026-01-02 Verbose logging for ADC debug
2026-01-02 Fix i2c bus spamming
2026-01-03 Fix MAX SN reading and re-add deep sleep
    [doorbell.yaml]
2026-01-05 Increase ADC resolution
2026-01-19 Base board Rev3
    [esphome-rf-doorbell.kicad_pcb, esphome-rf-doorbell.kicad_sch, remote.kicad_pcb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]
2026-04-18 Update docs, fix fuel gauge issue
    [esphome-rf-doorbell.kicad_pcb, esphome-rf-doorbell.kicad_sch]
2026-04-27 Rev 4
    [esphome-rf-doorbell.kicad_pcb, esphome-rf-doorbell.kicad_sch]
2026-04-29 Fix battery soc and improve sleep behavior
    [esphome-rf-doorbell.kicad_pcb]
2026-05-25 Add 30s bell press cooldown guard
    Prevents repeated triggers from sustained intercom line noise after
    RV1 replacement with fixed 4.7kΩ resistor. Uses last_bell_millis
    global (non-persistent, resets on cold boot) to reject re-triggers
    within 30 seconds of a real press.
    [doorbell.yaml]
2026-05-25 Fix stale timer comment (120s -> 300s, HA-controlled)
    [doorbell.yaml]

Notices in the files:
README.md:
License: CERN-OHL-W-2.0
